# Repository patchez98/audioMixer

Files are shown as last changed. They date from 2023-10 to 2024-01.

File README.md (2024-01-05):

# audioMixer (WIP)
Active audio mixer with powerful headphone amp. Current iteration is for 2 analog inputs, 1 output, but future plans include an integrated USB DAC and microphone feedback.

# Features
- Gain knobs for each channel
- Trimpot for setting max gain (necessary for decent volume control on easy-to-drive headphones)
- Capable of driving 600 ohm headphones

# Current Progress
- Built up a v0 board, here's the issues:
-- Input volume control is backwards, so the volume control is pretty bad. Primary gain control seems to work fine.
-- Multiple inputs causes various bad noises
--- This is probably some sort of ground loop issue, since I have 3 ground connections back to the PC. Next revision will have some options to disconnect grounds from jacks to see if that helps.
--- More power input filtering might help as well.
-- It doesn't seem to really drive my HD600s any better than my Fiio BTR3k, at least not in a way I can notice
--- I'm gonna have to add a proper +- 12V supply and use a much stronger opamp next time to see if that helps

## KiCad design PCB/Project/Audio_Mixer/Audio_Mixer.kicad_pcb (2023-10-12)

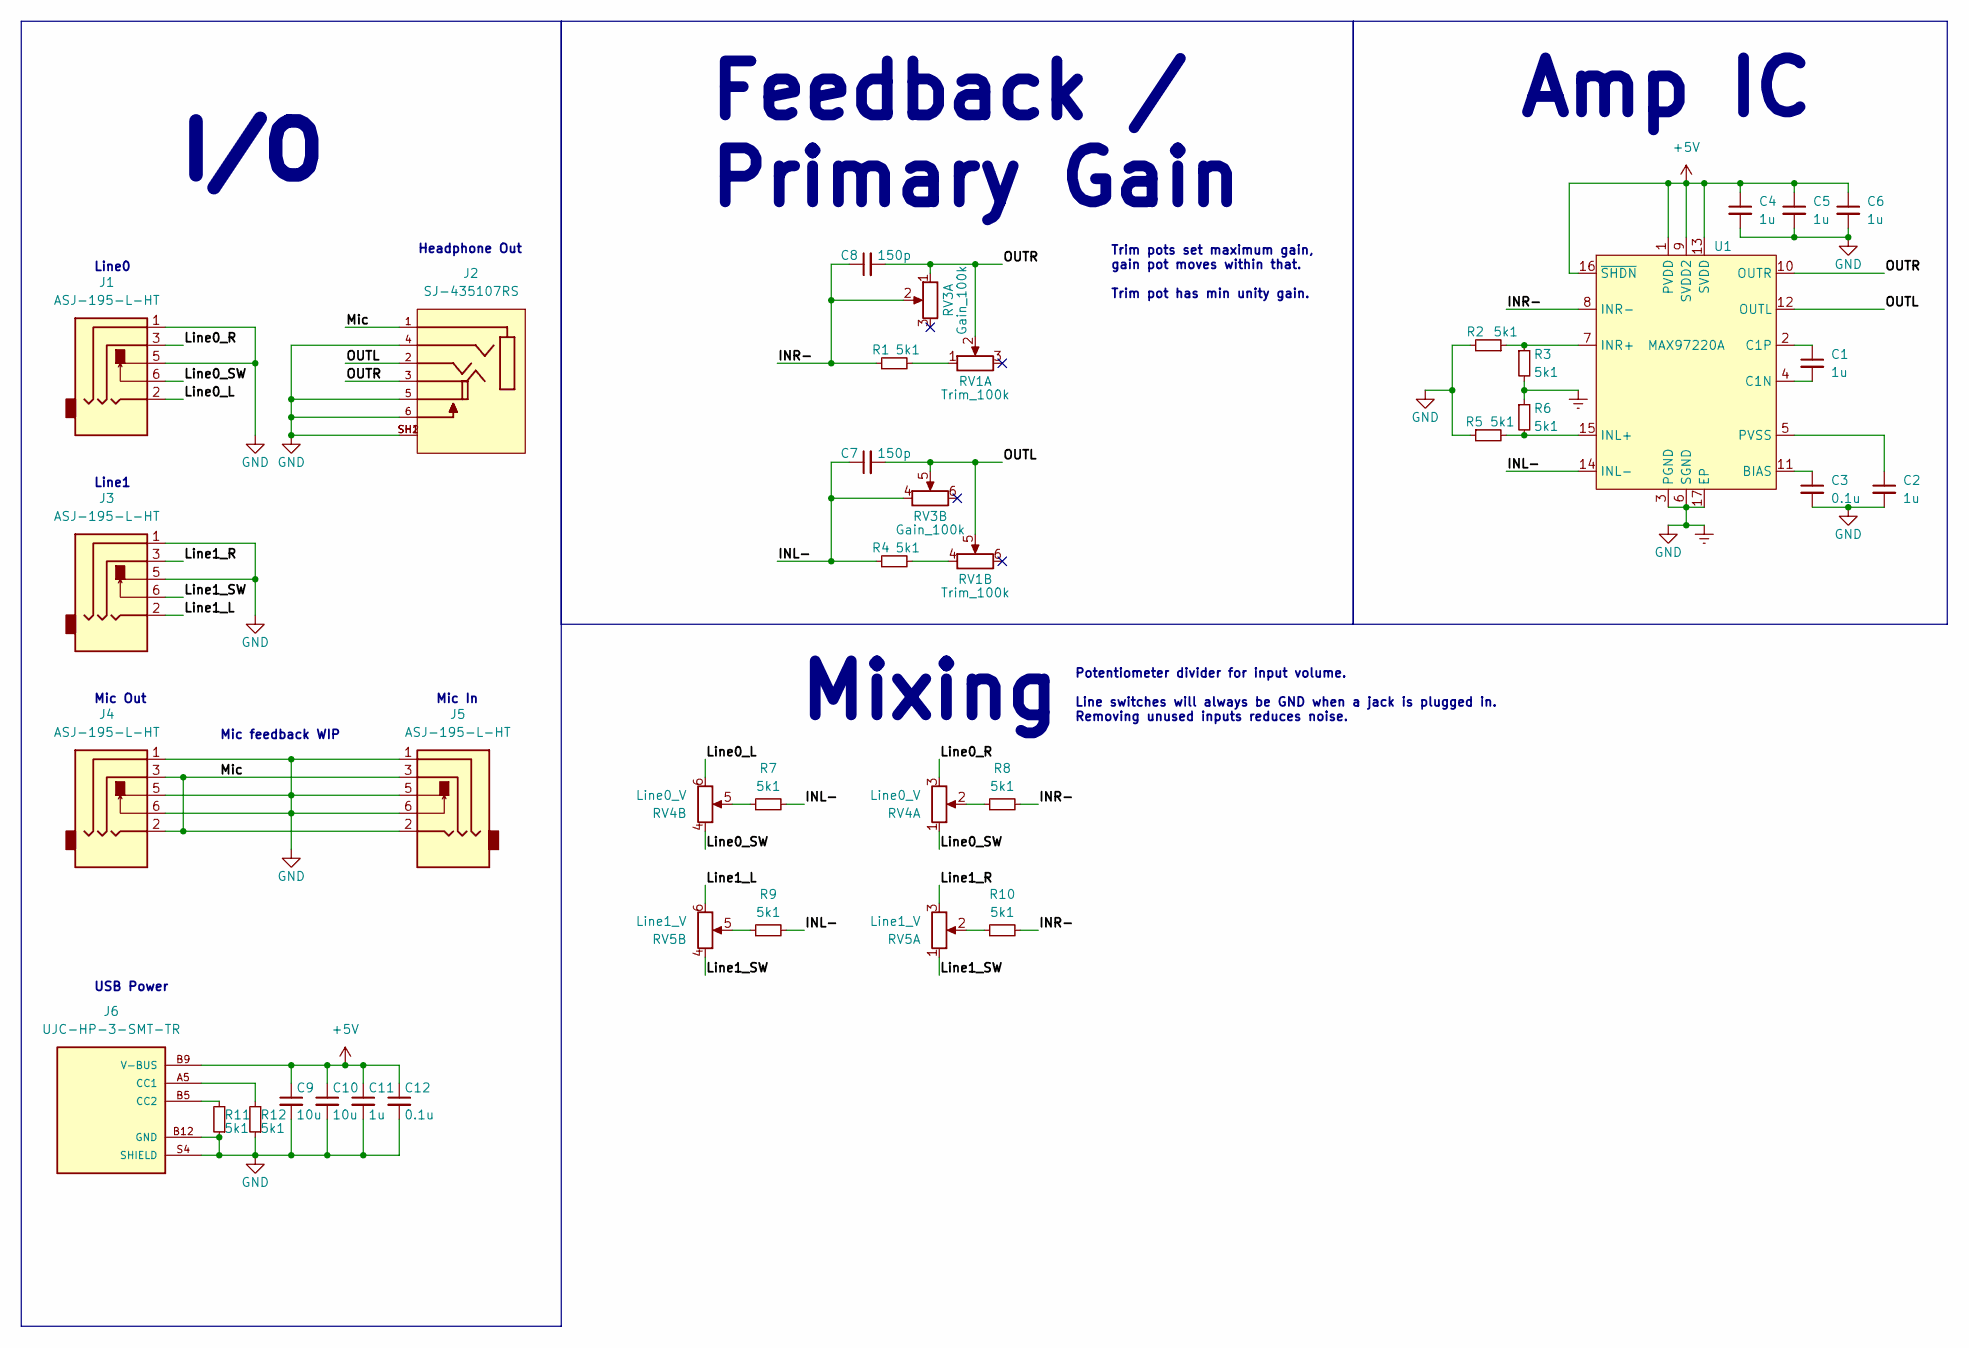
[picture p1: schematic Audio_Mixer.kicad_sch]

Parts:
C1, C2, C4, C5, C6, C11: 1u; C_0603_1608Metric
C3: 0.1u; C_0402_1005Metric
C7, C8: 150p; C_0402_1005Metric
C9, C10: 10u; C_0603_1608Metric
C12: 0.1u; C_0603_1608Metric
J1, J3, J4, J5: ASJ-195-L-HT; ASJ-195-X-HT
J2: SJ-435107RS; SJ-435107
J6: UJC-HP-3-SMT-TR; UJC-HP-3-SMT
R1, R2, R3, R4, R5, R6, R7, R8, R9, R10, R11, R12: 5k1; R_0402_1005Metric
RV1: Trim_100k; PS30-2
RV3: Gain_100k; RK14K124
RV4: Line0_V; RK14K124
RV5: Line1_V; RK14K124
U1: MAX97220A; TQFN-16-1EP_3x3mm_P0.5mm_EP1.23x1.23mm_ThermalVias

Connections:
+5V: C4.1, C5.1, C6.1, C9.1, C10.1, C11.1, C12.1, J6.A9 (V-BUS), J6.B9 (V-BUS), U1.1 (PVDD), U1.9 (SVDD2), U1.13 (SVDD), U1.16 (~SHDN)
/INL-: C7.1, R4.1, R7.2, R9.2, RV3.4, U1.14 (INL-)
/INR-: C8.1, R1.1, R8.2, R10.2, RV3.2, U1.8 (INR-)
/Line0_L: J1.2, RV4.6
/Line0_R: J1.3, RV4.3
/Line0_SW: J1.6, RV4.1, RV4.4
/Line1_L: J3.2, RV5.6
/Line1_R: J3.3, RV5.3
/Line1_SW: J3.6, RV5.1, RV5.4
/Mic: J2.1, J4.2, J4.3, J5.2, J5.3
/OUTL: C7.2, J2.2, RV1.5, RV3.5, U1.12 (OUTL)
/OUTR: C8.2, J2.3, RV1.2, RV3.1, U1.10 (OUTR)
Earth: C2.2, C3.2, C4.2, C5.2, C6.2, C9.2, C10.2, C11.2, C12.2, J1.1, J1.5, J2.4, J2.5, J2.6, J2.SH1, J2.SH2, J3.1, J3.5, J4.1, J4.5, J4.6, J5.1, J5.5, J5.6, J6.A12 (GND), J6.B12 (GND), J6.S1 (SHIELD), J6.S2 (SHIELD), J6.S3 (SHIELD), J6.S4 (SHIELD), R2.2, R3.2, R5.1, R6.1, R11.1, R12.1, U1.3 (PGND), U1.6 (SGND), U1.17 (EP)
unnamed: J6.A5 (CC1), R12.2
unnamed: J6.B5 (CC2), R11.2
unnamed: R1.2, RV1.1
unnamed: R4.2, RV1.4
unnamed: R7.1, RV4.5
unnamed: R8.1, RV4.2
unnamed: R9.1, RV5.5
unnamed: R10.1, RV5.2
unnamed: C3.1, U1.11 (BIAS)
unnamed: C1.2, U1.4 (C1N)
unnamed: C1.1, U1.2 (C1P)
unnamed: R5.2, R6.2, U1.15 (INL+)
unnamed: R2.1, R3.1, U1.7 (INR+)
unnamed: C2.1, U1.5 (PVSS)

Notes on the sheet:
Feedback / Primary Gain
Mixing
Trim pots set maximum gain, gain pot moves within that. Trim pot has min unity gain.
I/O
Headphone Out
Mic In
Mic feedback WIP
Amp IC
Line0
Potentiometer divider for input volume. Line switches will always be GND when a jack is plugged in. Removing unused inputs reduces noise.
Line1
Mic Out
USB Power

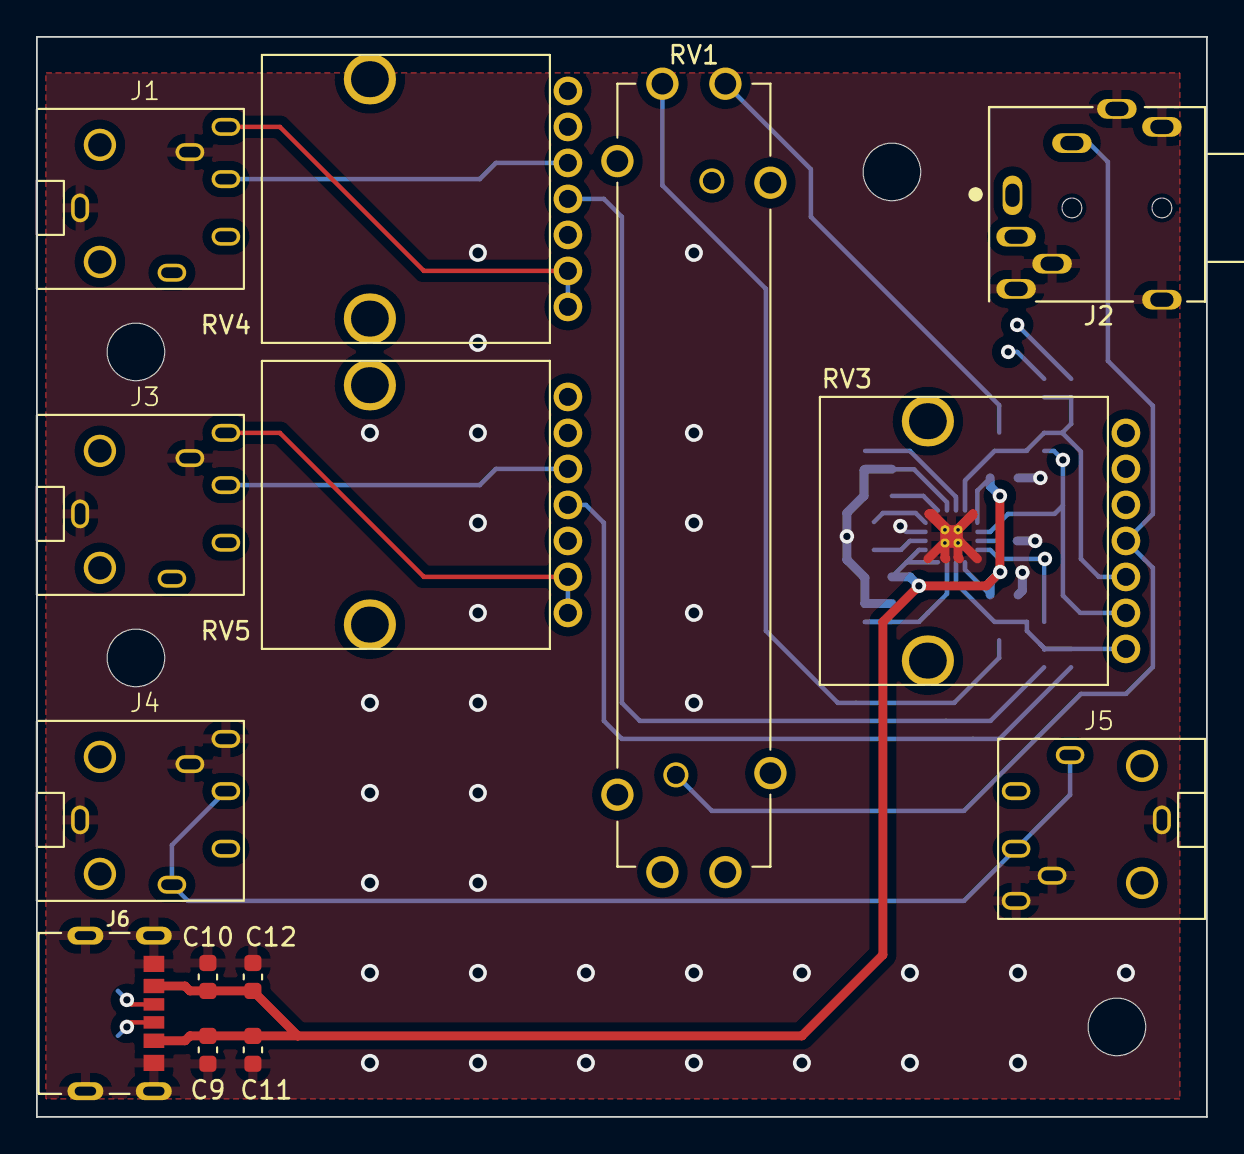
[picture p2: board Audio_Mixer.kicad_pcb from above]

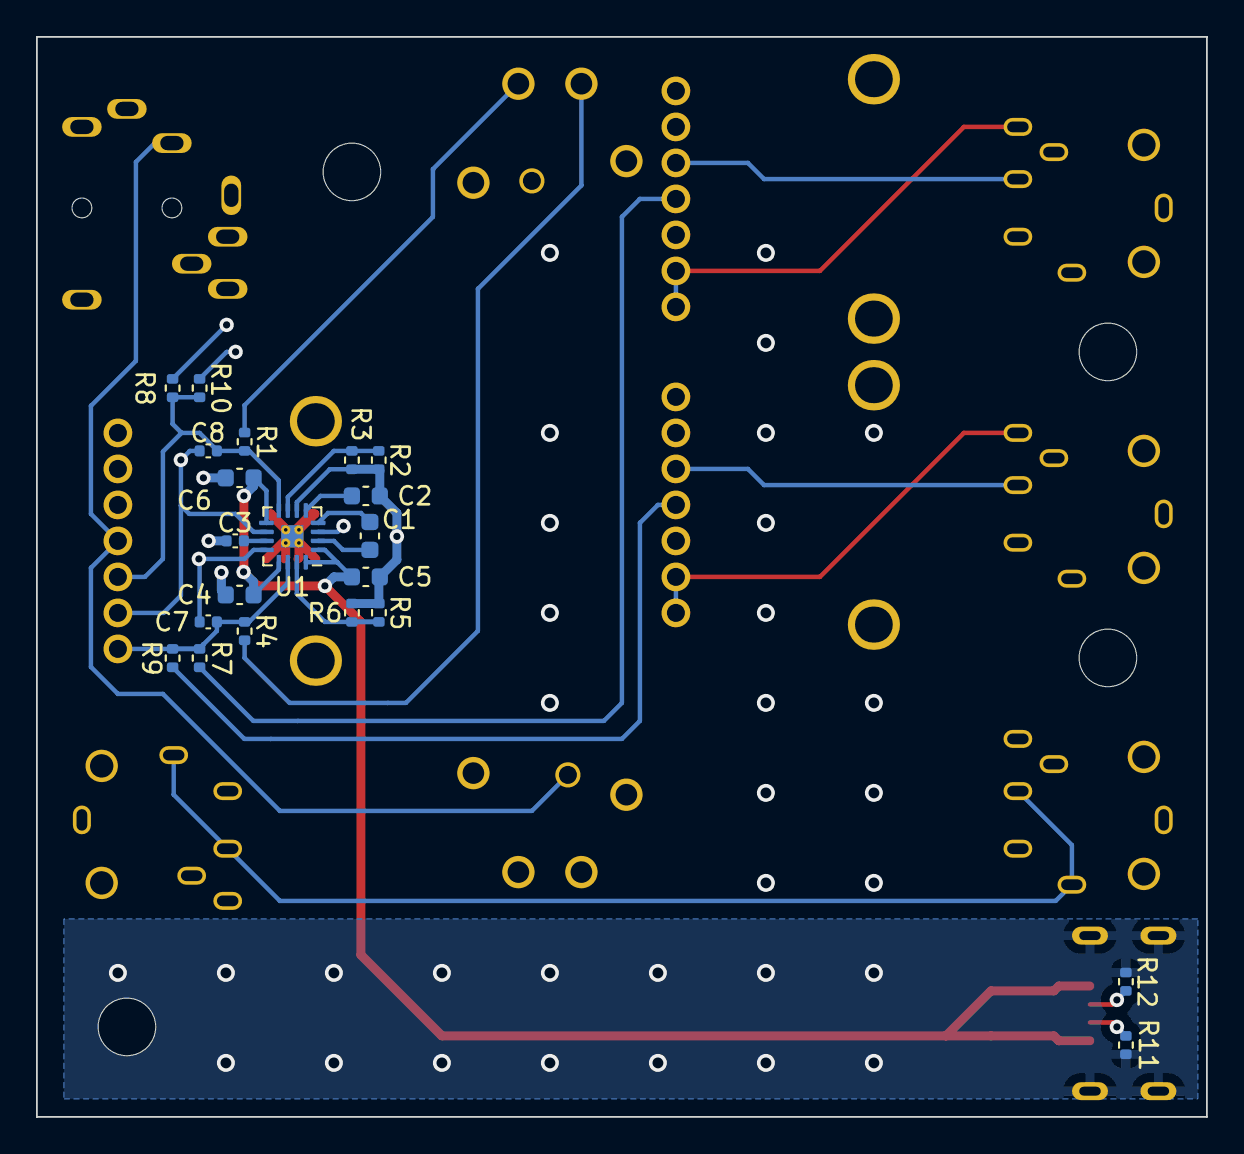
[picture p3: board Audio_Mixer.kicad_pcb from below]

Board: 4 copper layers, 65.0 x 60.0 mm, 35 parts (21 on the bottom side), 27 nets.

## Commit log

2023-09-16 Started work on project. Schematic mostly done for v0.
    [Audio_Mixer.kicad_pcb, Audio_Mixer.kicad_sch]
2023-10-12 Boards ordered for v0; gerbs included
    [Audio_Mixer.kicad_pcb, Audio_Mixer.kicad_sch]
